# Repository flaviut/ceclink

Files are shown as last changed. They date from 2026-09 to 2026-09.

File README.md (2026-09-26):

# CECLink

The CECLink is a small device that can be used to allow a Linux computer to control a TV using the CEC protocol over HDMI. This is particularly helpful for HTPCs, which often do not have the required hardware to do so built-in.

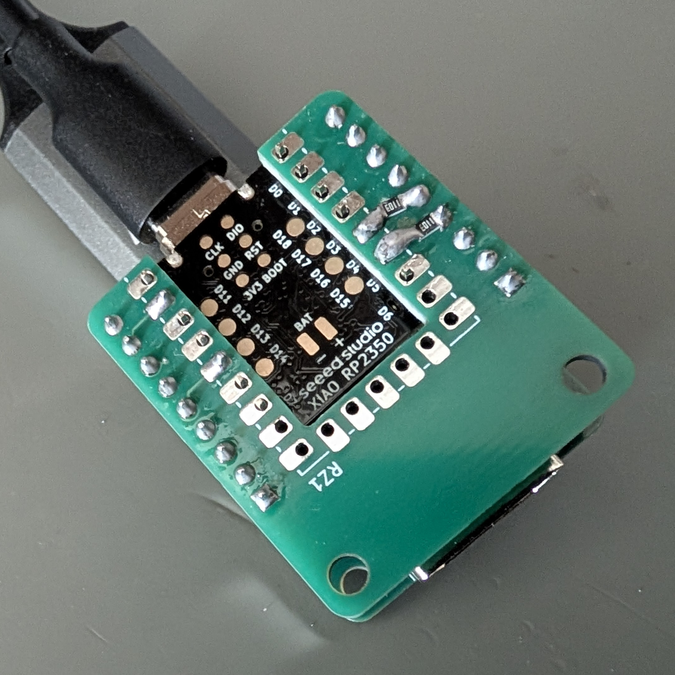
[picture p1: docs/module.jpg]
photo of the device


## Why?

What's unique about this device is that it supports higher HDMI bandwidths. It is designed to work with and tested on a 4k, 10-bit HDR, 60FPS signal. This is done through following best practices for high-speed data lines.

While others devices look like this, and are made on a standard PCB (thanks [karl for the photo](https://karlquinsland.com/pulse-eight-hdmi-cec-injector-teardown/)):

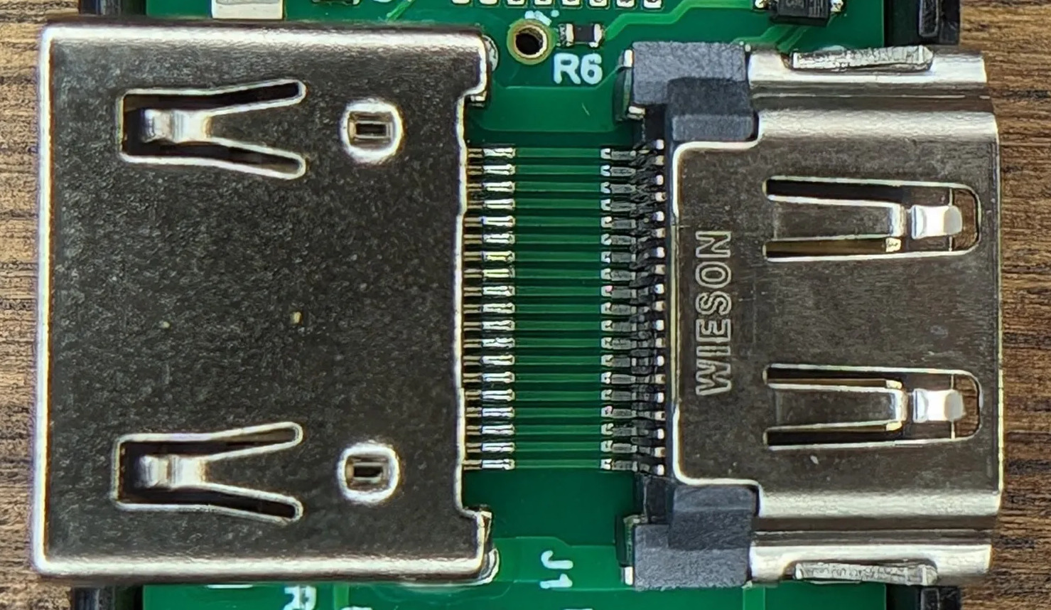
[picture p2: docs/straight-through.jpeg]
Wires passing straight through a HDMI connector


This project's design looks a little different, as it follows best practices in the dark arts of RF design:

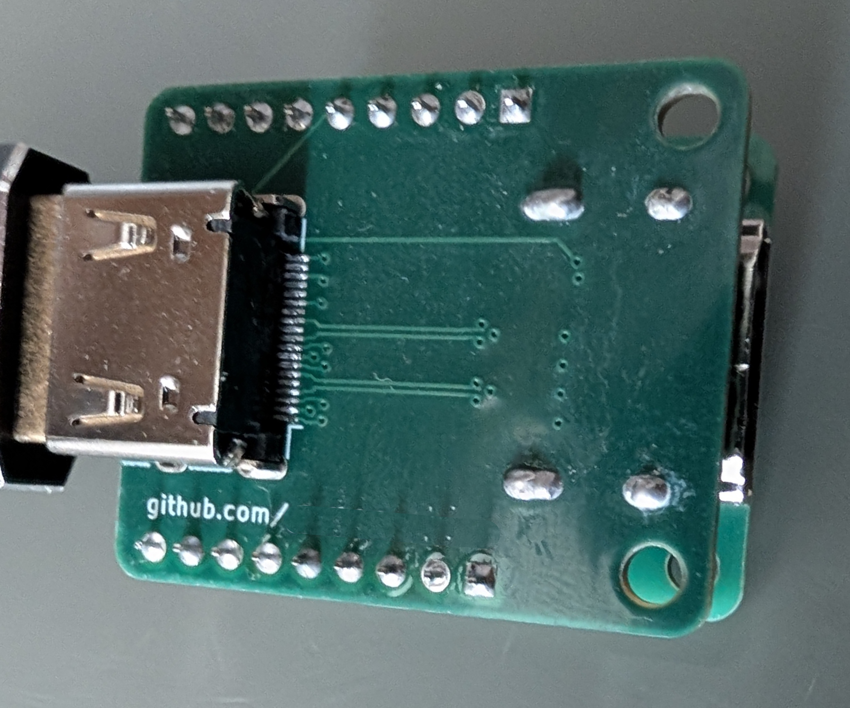
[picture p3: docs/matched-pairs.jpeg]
matched pairs for video lines


To be clear, this is not a secret technique! I would love to see others use this technique, and offer an updated commercial version of this device! All the details on how it works are in this source repo under `pcb/`, and I would be happy to talk about it.

## Making your own

### PCB

The hardware is split across two KiCad projects under [`pcb/`](pcb). You will
need to have *both* these boards produced:

* [`pcb/hdmi-breakout`](pcb/hdmi-breakout) — the HDMI passthrough that breaks
  out the CEC and DDC signals. It is a 4-layer board; order it with the
  **JLC04161H-7628 stackup**. The precise stackup is *crucial* for it to work.
* [`pcb/xiao-rp2350-adaptor`](pcb/xiao-rp2350-adaptor) — a simple breakout for the XIAO RP2350
  that connects to the HDMI breakout. This is an ordinary 2-layer board with
  no controlled-impedance requirement, so any standard stackup is fine.

The [latest release](https://github.com/flaviut/ceclink/releases/latest) has
ready-to-order Gerber and drill archives: `adapter.zip` for the XIAO RP2350 adapter
and `hdmi-breakout.zip` for the HDMI board.

Gerber and drill archives for each board can be generated with
[`jlcpcb_fab.py`](jlcpcb_fab.py).

Additional BOM (parts to source separately on top of the fabricated boards):

| Count | Part |
| ----- | ---- |
| 2 | HDMI Type-A receptacle (Molex 208658-1001, LCSC C138388) |
| 2 | 0603 100kΩ resistor |
| 1 | XIAO RP2350 |
| 2 | 1×9 2.54mm male pin header strip |
| 2 | 1×9 2.54mm female header / socket strip |
| 2 | M3 × 16mm socket head cap screw |
| 2 | M3 nut |

Remember that you can easily cut a longer 2.54mm header to size with some snips.

### Initial flash

Download `firmware.uf2` from the
[latest release](https://github.com/flaviut/ceclink/releases/latest).

Hold the BOOT button while connecting the USB cable. Once powered, you should see a new drive on your computer. Copy-paste the `.uf2` file over, and your device should be flashed.

#### CLI alternative

```sh
picotool load -v -x ceclink.uf2
```

### Operating system integration

This project tries to make use of the operating system drivers for the bulk of the integration, but this is unfortunately not fully sufficient. On Linux, `inputattach` connects the CEC serial interface to the Pulse-Eight kernel driver. A separate helper reads the HDMI physical address from the status interface and applies it to the kernel's CEC device.

#### Generic Linux installation

These instructions use systemd and udev to start the adapter automatically when it is plugged in, including after reboot.

Install the dependencies for your distribution:

| Distribution family | Install command |
| --- | --- |
| Debian / Ubuntu | `sudo apt install curl inputattach python3-serial ddcutil v4l-utils` |
| Fedora | `sudo dnf install curl linuxconsoletools python3-pyserial ddcutil v4l-utils` |
| Arch Linux | `sudo pacman -S curl linuxconsole python-pyserial ddcutil v4l-utils` |

Download the physical-address helper into `/opt/ceclink` and configure the kernel modules to load at boot:

```sh
sudo install -d -m755 /opt/ceclink
sudo curl --fail --location https://raw.githubusercontent.com/flaviut/ceclink/HEAD/nix/physical-address.py -o /opt/ceclink/physical-address.py
sudo curl --fail --location https://raw.githubusercontent.com/flaviut/ceclink/HEAD/linux/ceclink.conf -o /etc/modules-load.d/ceclink.conf
sudo modprobe pulse8-cec
sudo modprobe i2c-dev
```

If `modprobe pulse8-cec` reports that the module is missing, your kernel needs the Pulse-Eight CEC driver (`CONFIG_USB_PULSE8_CEC`). Install your distribution's additional kernel modules package or use a kernel that includes this driver before continuing.

Install the two systemd service templates. The first attaches the CEC control port to the kernel driver; the second keeps the kernel's HDMI physical address synchronized with the adapter:

```sh
sudo curl --fail --location https://raw.githubusercontent.com/flaviut/ceclink/HEAD/linux/pulse8-cec-inputattach@.service -o /etc/systemd/system/pulse8-cec-inputattach@.service

sudo curl --fail --location https://raw.githubusercontent.com/flaviut/ceclink/HEAD/linux/ceclink-physical-address@.service -o /etc/systemd/system/ceclink-physical-address@.service
```

Install the udev rules that start these services for the correct USB interfaces. Interface `00` carries CEC commands; interface `02` carries physical-address status:

```sh
sudo curl --fail --location https://raw.githubusercontent.com/flaviut/ceclink/HEAD/linux/99-ceclink.rules -o /etc/udev/rules.d/99-ceclink.rules
sudo systemctl daemon-reload
sudo udevadm control --reload-rules
```

Connect the adapter in the HDMI path, then unplug and reconnect its USB cable. udev starts both services automatically; no `systemctl enable` is needed. Check that they are running and that the CEC device has a physical address:

```sh
systemctl status 'pulse8-cec-inputattach@*' 'ceclink-physical-address@*'
sudo cec-ctl -d /dev/cec0
```

If you have multiple CEC devices, substitute the adapter's `/dev/cecN` path. To inspect service logs:

```sh
journalctl -b -u 'pulse8-cec-inputattach@*' -u 'ceclink-physical-address@*'
```

#### NixOS integration

Things are much easier on NixOS. Add this repository to your system flake's inputs:

```nix
inputs.ceclink.url = "github:flaviut/ceclink";
```

Include `ceclink` in your flake's `outputs` arguments and add its module to the host's existing `nixosSystem` module list:

```nix
outputs = { nixpkgs, ceclink, ... }: {
  nixosConfigurations.myhost = nixpkgs.lib.nixosSystem {
    modules = [
      ./configuration.nix
      ceclink.nixosModules.default
    ];
  };
};
```

## Development

### Building

```sh
nix develop
cargo build --locked --profile release-with-debug
picotool uf2 convert target/thumbv8m.main-none-eabihf/release-with-debug/ceclink -t elf ceclink.uf2
```

If direnv is enabled in your shell, run `direnv allow` once in this directory to enter the flake dev shell automatically.

For a reproducible production artifact:

```sh
nix build .#firmware
ls result/ceclink.{uf2,elf}
```

Format the Nix and Rust sources with `nix fmt`.

## Connections

| XIAO pin | RP2350 GPIO | Role |
| --- | ---: | --- |
| D9 | GPIO4 | Bidirectional CEC, open drain |
| D4 | GPIO6 | DDC SDA input only |
| D5 | GPIO7 | DDC SCL input only |

D4 and D5 are receive-only GPIO inputs, not I²C master pins. Use a 100kΩ resistor between the HDMI bus and the RP2350.

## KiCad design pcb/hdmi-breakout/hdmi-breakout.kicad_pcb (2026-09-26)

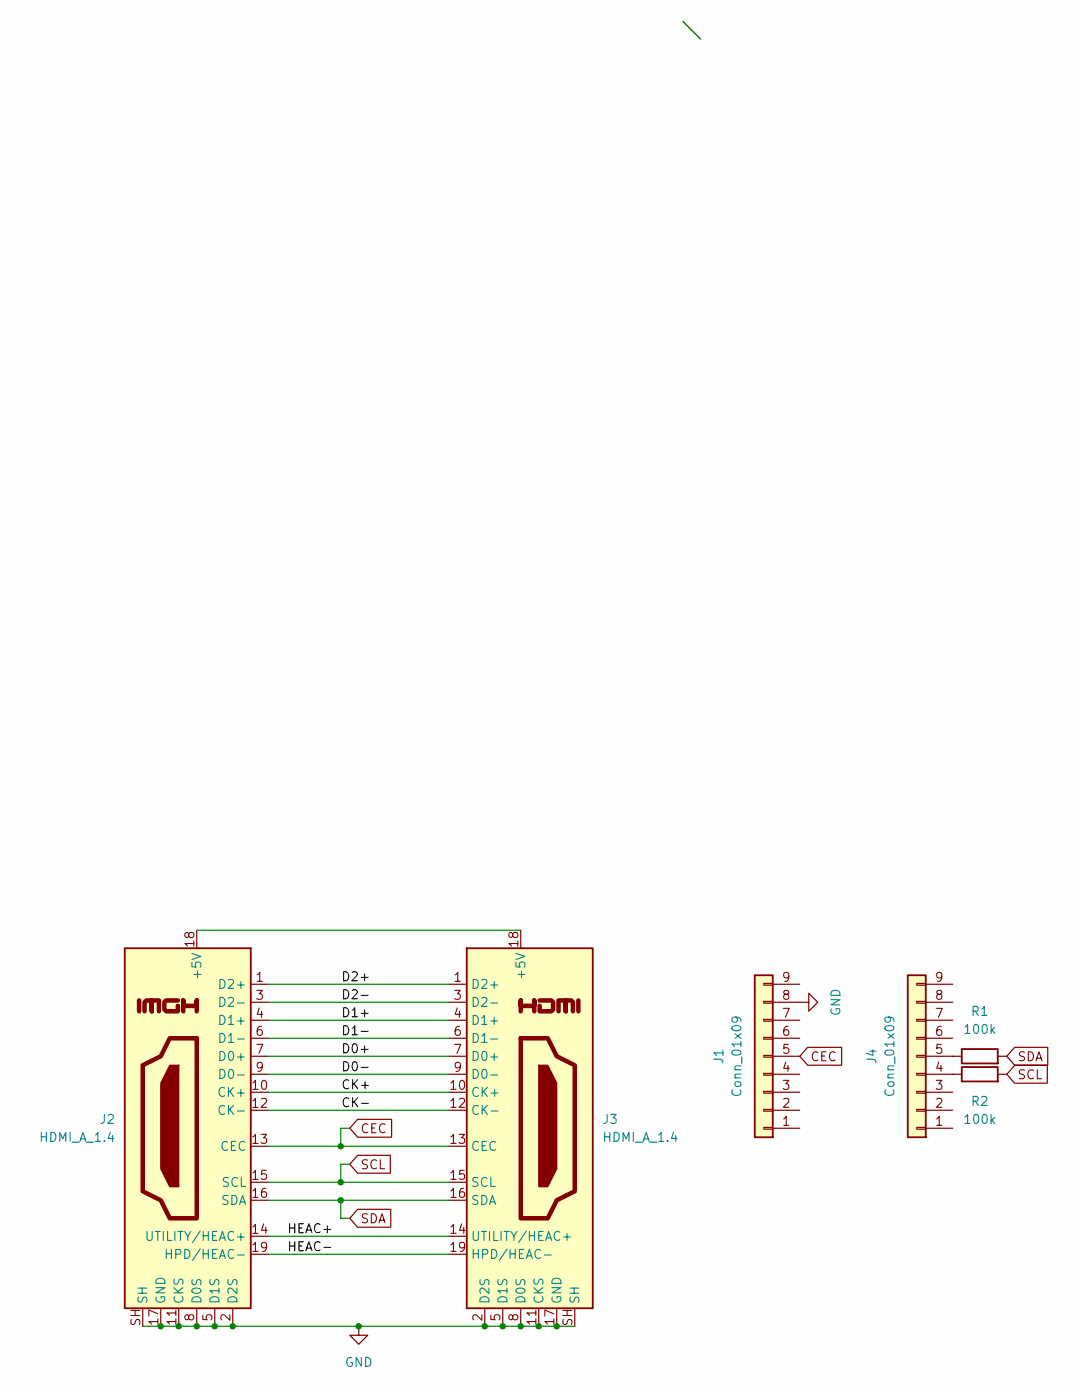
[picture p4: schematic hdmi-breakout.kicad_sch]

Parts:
J1, J4: Conn_01x09; PinHeader_1x09_P2.54mm_Vertical; LCSC C2897372
J2, J3: HDMI_A_1.4; HDMI_A_Molex_208658-1001_Horizontal; LCSC C138388
R1, R2: 100k; R_0603_1608Metric_Pad0.98x0.95mm_HandSolder; LCSC C25803

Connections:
/CK+: J2.10 (CK+), J3.10 (CK+)
/CK-: J2.12 (CK-), J3.12 (CK-)
/D0+: J2.7 (D0+), J3.7 (D0+)
/D0-: J2.9 (D0-), J3.9 (D0-)
/D1+: J2.4 (D1+), J3.4 (D1+)
/D1-: J2.6 (D1-), J3.6 (D1-)
/D2+: J2.1 (D2+), J3.1 (D2+)
/D2-: J2.3 (D2-), J3.3 (D2-)
/HEAC+: J2.14 (UTILITY/HEAC+), J3.14 (UTILITY/HEAC+)
/HEAC-: J2.19 (HPD/HEAC-), J3.19 (HPD/HEAC-)
CEC: J1.5, J2.13 (CEC), J3.13 (CEC)
GND: J1.8, J2.2 (D2S), J2.5 (D1S), J2.8 (D0S), J2.11 (CKS), J2.17 (GND), J2.SH, J3.2 (D2S), J3.5 (D1S), J3.8 (D0S), J3.11 (CKS), J3.17 (GND), J3.SH
unnamed: J2.18 (+5V), J3.18 (+5V)
unnamed: J4.4, R2.1
unnamed: J4.5, R1.1
SCL: J2.15 (SCL), J3.15 (SCL), R2.2
SDA: J2.16 (SDA), J3.16 (SDA), R1.2

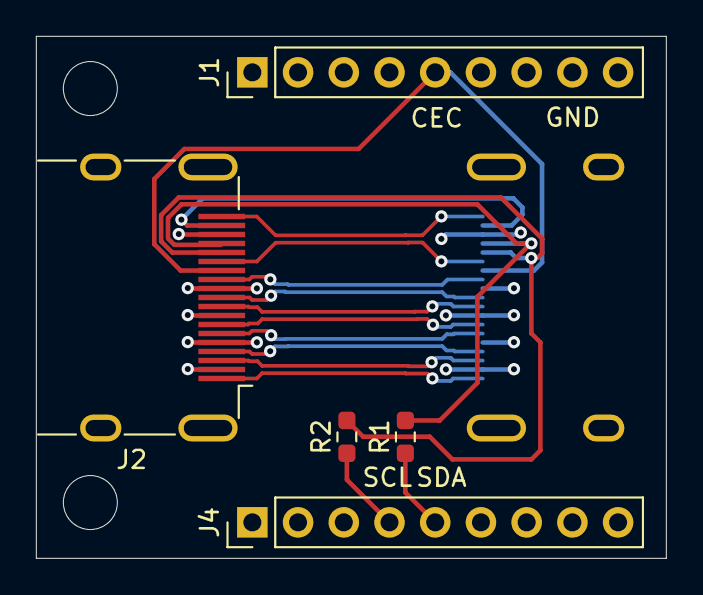
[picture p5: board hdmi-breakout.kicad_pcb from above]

Board: 4 copper layers, 35.0 x 29.0 mm, 6 parts (1 on the bottom side), 17 nets.

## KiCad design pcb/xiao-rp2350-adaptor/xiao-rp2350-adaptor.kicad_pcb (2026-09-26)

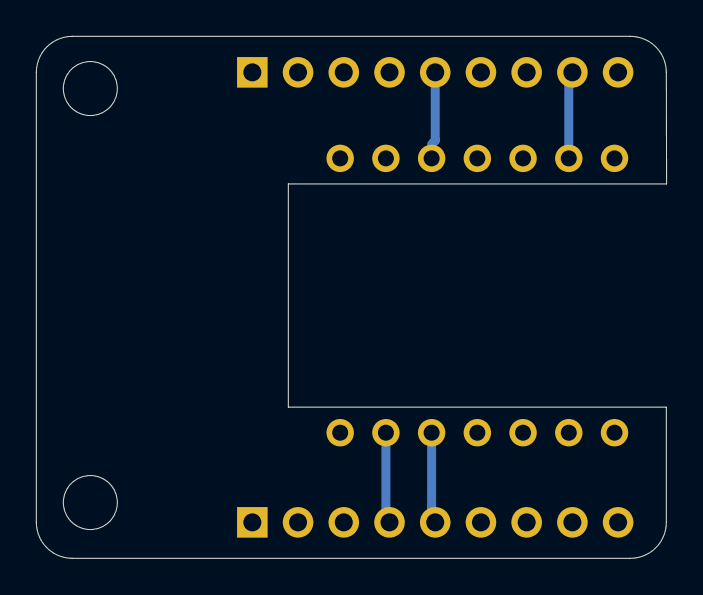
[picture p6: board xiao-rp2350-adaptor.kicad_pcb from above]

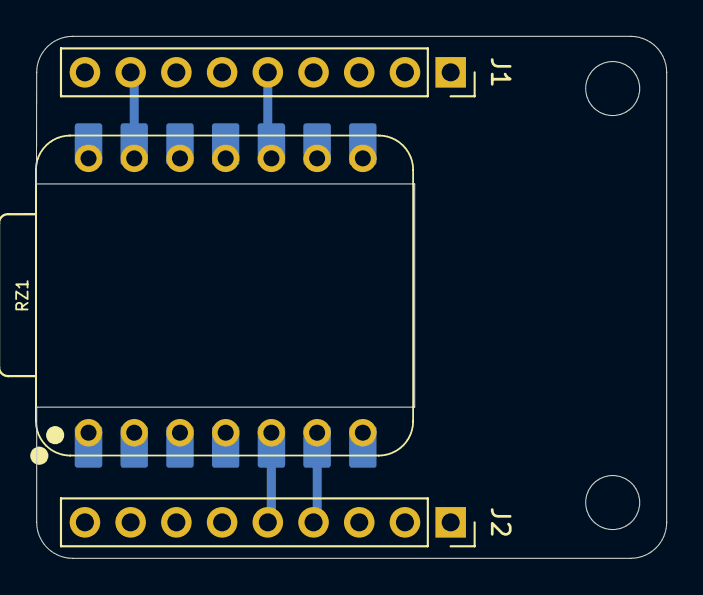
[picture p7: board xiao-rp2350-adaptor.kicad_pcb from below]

Board: 2 copper layers, 35.0 x 29.0 mm, 3 parts (3 on the bottom side), 4 nets.

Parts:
J1, J2: Conn_01x09; PinSocket_1x09_P2.54mm_Vertical
RZ1: XIAO-RP2350; XIAO-RP2350-DIP

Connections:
CEC: J1.5, RZ1.10 (GPIO4_D9_SPI0_MISO)
GND: J1.8, RZ1.13 (GND)
SCL: J2.4, RZ1.6 (GPIO7_D5_SCL1)
SDA: J2.5, RZ1.5 (GPIO6_D4_SDA1)

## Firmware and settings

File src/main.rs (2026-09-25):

#![no_std]
#![no_main]

use hal::{
    clocks::Clock,
    gpio::Pins,
    multicore::{Multicore, Stack},
    sio::Sio,
};
use panic_halt as _;
use rp235x_hal as hal;
use usb_device::{class_prelude::UsbBusAllocator, prelude::*};
use usbd_serial::SerialPort;

mod cec;
mod ddc;
mod ddc_protocol;
mod debug_port;
mod pulse8;
mod status_led;
mod transport;
mod usb_reset;

#[unsafe(link_section = ".start_block")]
#[used]
static IMAGE_DEF: hal::block::ImageDef = hal::block::ImageDef::secure_exe();
static CORE1_STACK: Stack<4096> = Stack::new();

fn usb_serial_number(buffer: &mut [u8; 16]) -> Option<&str> {
    let chip = hal::rom_data::sys_info_api::chip_info().ok().flatten()?;
    // The HAL's wafer_id field holds the high 32 bits of the RP2350 chip ID.
    for (index, word) in [chip.wafer_id, chip.device_id].into_iter().enumerate() {
        for digit in 0..8 {
            let nibble = ((word >> (28 - digit * 4)) & 0xf) as u8;
            buffer[index * 8 + digit] = if nibble < 10 {
                b'0' + nibble
            } else {
                b'A' + nibble - 10
            };
        }
    }
    core::str::from_utf8(buffer).ok()
}

#[hal::entry]
fn main() -> ! {
    let mut pac = hal::pac::Peripherals::take().unwrap();
    let mut watchdog = hal::Watchdog::new(pac.WATCHDOG);
    let clocks = hal::clocks::init_clocks_and_plls(
        12_000_000,
        pac.XOSC,
        pac.CLOCKS,
        pac.PLL_SYS,
        pac.PLL_USB,
        &mut pac.RESETS,
        &mut watchdog,
    )
    .unwrap();
    let timer = hal::Timer::new_timer0(pac.TIMER0, &mut pac.RESETS, &clocks);

    let mut sio = Sio::new(pac.SIO);
    let pins = Pins::new(
        pac.IO_BANK0,
        pac.PADS_BANK0,
        sio.gpio_bank0,
        &mut pac.RESETS,
    );
    let cec_pin = pins.gpio4.into_floating_input(); // XIAO D9
    let sda = pins.gpio6.into_floating_input(); // XIAO D4
    let scl = pins.gpio7.into_floating_input(); // XIAO D5
    let rgb_data = pins.gpio22.into_floating_input();
    let rgb_power = pins.gpio23.into_floating_input();
    let mut led = status_led::StatusLed::new(
        rgb_data,
        rgb_power,
        pac.PIO1,
        &mut pac.RESETS,
        clocks.system_clock.freq().to_Hz(),
    );
    let mut ddc = ddc::init(sda, scl, pac.PIO0, &mut pac.RESETS);
    unsafe {
        hal::arch::interrupt_enable();
    }

    let mut multicore = Multicore::new(&mut pac.PSM, &mut pac.PPB, &mut sio.fifo);
    let usb_timer = timer;
    multicore.cores()[1]
        .spawn(CORE1_STACK.take().unwrap(), move || {
            cec::run(cec_pin, timer)
        })
        .unwrap();

    let usb_bus = UsbBusAllocator::new(hal::usb::UsbBus::new(
        pac.USB,
        pac.USB_DPRAM,
        clocks.usb_clock,
        true,
        &mut pac.RESETS,
    ));
    let mut serial =
        SerialPort::new_with_interface_names(&usb_bus, Some("Pulse-Eight CEC control"), None);
    let mut debug_serial =
        SerialPort::new_with_interface_names(&usb_bus, Some("CECLink status"), None);
    let mut usb_reset = usb_reset::UsbReset::new(&usb_bus);
    let mut serial_number_buffer = [0u8; 16];
    let mut strings = StringDescriptors::default()
        .manufacturer("CECLink")
        .product("RP2350 HDMI CEC Adapter");
    if let Some(serial_number) = usb_serial_number(&mut serial_number_buffer) {
        strings = strings.serial_number(serial_number);
    }
    let mut device = UsbDeviceBuilder::new(&usb_bus, UsbVidPid(0x2548, 0x1002))
        .strings(&[strings])
        .unwrap()
        .composite_with_iads()
        .device_release(0x0010) // USB BCD version shown by fwupd.
        .build();

    let mut protocol = pulse8::Protocol::new();
    let mut pending_output = None;
    let mut debug_output = debug_port::DebugOutput::new();
    let mut usb_bootsel_requested_at = None;
    loop {
        ddc.poll();
        led.update(ddc.led_state());
        let _ = device.poll(&mut [&mut serial, &mut debug_serial, &mut usb_reset]);
        let mut bytes = [0u8; 64];
        if let Ok(count) = serial.read(&mut bytes) {
            for &byte in &bytes[..count] {
                protocol.input_byte(byte);
            }
        }
        while let Some(event) = transport::pop_event() {
            protocol.event(event);
        }
        protocol.set_physical_address(ddc.physical_address());
        let mut debug_bytes = [0u8; 32];
        if let Ok(count) = debug_serial.read(&mut debug_bytes) {
            for &byte in &debug_bytes[..count] {
                debug_output.input_byte(byte);
            }
        }
        debug_output.poll(&mut debug_serial, usb_timer.get_counter().ticks(), &ddc);
        if usb_reset.take_bootsel_request() {
            usb_bootsel_requested_at = Some(usb_timer.get_counter_low());
        }
        let usb_bootsel_ready = usb_bootsel_requested_at
            .is_some_and(|at| usb_timer.get_counter_low().wrapping_sub(at) >= 50_000);
        if usb_bootsel_ready {
            hal::reboot::reboot(
                hal::reboot::RebootKind::BootSel {
                    picoboot_disabled: false,
                    msd_disabled: false,
                },
                hal::reboot::RebootArch::Arm,
            );
        }
        if pending_output.is_none() {
            pending_output = protocol.next_output();
        }
        if let Some(byte) = pending_output {
            if serial.write(&[byte]).is_ok() {
                pending_output = None;
            }
        }
    }
}

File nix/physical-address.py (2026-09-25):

"""Apply CECLink status records to the Linux CEC adapter on the same USB device."""

import argparse
import array
import fcntl
import logging
import os
import subprocess
import time
from pathlib import Path


# Linux CEC UAPI ioctl numbers on the supported x86_64 and aarch64 systems.
CEC_ADAP_G_PHYS_ADDR = 0x80026101
CEC_ADAP_S_PHYS_ADDR = 0x40026102
UNKNOWN_ADDRESS = 0xFFFF
MAX_EDID_READS = 3
EDID_RETRY_DELAY = 5.0


def parse_status(line):
    try:
        fields = dict(field.split("=", 1) for field in line.decode("ascii").strip().split("\t"))
        if set(fields) != {"status_version", "physical_address"}:
            return None
        if fields["status_version"] != "1":
            return None
        address = int(fields["physical_address"])
    except (UnicodeError, ValueError):
        return None
    if not 0 <= address <= 0xFFFF:
        return None
    if address != 0xFFFF:
        zero = False
        for shift in (12, 8, 4, 0):
            nibble = (address >> shift) & 15
            if zero and nibble:
                return None
            zero |= nibble == 0
    return address


def usb_parent(path):
    path = path.resolve(strict=True)
    for parent in (path, *path.parents):
        if (parent / "idVendor").exists() and (parent / "idProduct").exists():
            return parent
    raise OSError(f"No USB parent for {path}")


def cec_sysfs_path(device, sysfs):
    number = device.stat().st_rdev
    return sysfs / "dev/char" / f"{os.major(number)}:{os.minor(number)}"


def matching_cec(tty, sysfs=Path("/sys"), devices=Path("/dev")):
    usb = usb_parent(sysfs / "class/tty" / tty)
    matches = []
    for device in devices.glob("cec*"):
        if not device.name[3:].isdigit():
            continue
        try:
            if usb_parent(cec_sysfs_path(device, sysfs)) == usb:
                matches.append(device)
        except OSError:
            continue
    # Never guess if a driver has not attached or multiple adapters match.
    return matches[0] if len(matches) == 1 else None


def apply_address(device, address):
    with device.open("rb+", buffering=0) as port:
        current = array.array("H", [0])
        fcntl.ioctl(port, CEC_ADAP_G_PHYS_ADDR, current, True)
        if current[0] == address:
            return False
        fcntl.ioctl(port, CEC_ADAP_S_PHYS_ADDR, array.array("H", [address]))
    return True


def synchronize(tty, address):
    device = matching_cec(tty)
    if device is not None and apply_address(device, address):
        logging.info("%s physical address: %04x", device, address)


class AddressFilter:
    """Let EDID rereads finish before publishing a topology change."""

    def __init__(self):
        self.candidate = None
        self.since = 0.0

    def settled(self, address, now):
        if address != self.candidate:
            self.candidate = address
            self.since = now
        delay = 2.0 if address == 0xFFFF else 0.5
        return now - self.since >= delay


class EdidRecovery:
    """Bound active reads while firmware has not captured an address."""

    def __init__(self):
        self.attempts = 0
        self.next_attempt = 0.0

    def observe(self, address, now):
        if address != UNKNOWN_ADDRESS:
            self.attempts = 0
            self.next_attempt = 0.0
            return False
        if self.attempts >= MAX_EDID_READS or now < self.next_attempt:
            return self.attempts < MAX_EDID_READS or now < self.next_attempt
        self.attempts += 1
        try:
            result = subprocess.run(
                [
                    "ddcutil",
                    "--edid-read-size=256",
                    "--disable-try-get-edid-from-sysfs",
                    "detect",
                ],
                capture_output=True,
                timeout=20,
                check=False,
            )
            # detect scans every display bus. Some displays lack DDC/CI;
            # firmware status confirms whether EDID contained an address.
            logging.info("DDC EDID scan exited %d", result.returncode)
        except (OSError, subprocess.TimeoutExpired) as error:
            logging.warning("DDC EDID read deferred: %s", error)
        self.next_attempt = time.monotonic() + EDID_RETRY_DELAY
        return True


def ready_address(address_filter, recovery, address, now):
    # A DDC read briefly clears the firmware address. Wait for the status to
    # settle before starting another read or resetting the retry budget.
    if not address_filter.settled(address, now):
        return None
    if recovery.observe(address, now):
        return None
    return address


def main():
    import serial

    parser = argparse.ArgumentParser(description=__doc__)
    parser.add_argument("tty", help="CECLink status TTY name, e.g. ttyACM1")
    args = parser.parse_args()
    logging.basicConfig(level=logging.INFO, format="%(message)s")
    address_filter = AddressFilter()
    recovery = EdidRecovery()
    # pyserial asserts DTR so the device emits status records.
    with serial.Serial(f"/dev/{args.tty}", timeout=2, exclusive=True) as port:
        while True:
            line = port.read_until(b"\n", size=1024)
            if not line.endswith(b"\n"):
                continue
            address = parse_status(line)
            if address is None:
                continue
            now = time.monotonic()
            address = ready_address(address_filter, recovery, address, now)
            if address is None:
                continue
            try:
                synchronize(args.tty, address)
            except OSError as error:
                # The next periodic record retries device enumeration and
                # address writes, even if the physical address is unchanged.
                logging.warning("Physical address update deferred: %s", error)


if __name__ == "__main__":
    main()

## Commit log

2026-09-25 Use binary serde for Pulse-Eight wire payloads
2026-09-25 Simplify Pulse-Eight wire encoding
2026-09-25 Package Pulse-Eight CEC driver as kernel module overlay
2026-09-25 Fix automatic EDID recovery after firmware restart
    [physical-address.py]
2026-09-25 update docs
    [hdmi-breakout.kicad_pcb, hdmi-breakout.kicad_sch, hdmi-breakout.sch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]
2026-09-25 correct hardware bugs
    [hdmi-breakout.kicad_pcb, hdmi-breakout.kicad_sch, rp2040-adaptor.kicad_pcb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]
2026-09-25 update name
    [hdmi-breakout.kicad_pcb]
2026-09-26 clarify docs
    [xiao-rp2350-adaptor.kicad_pcb, xiao-rp2350-adaptor.kicad_sch]
2026-09-26 update BOM
    [hdmi-breakout.kicad_pcb, hdmi-breakout.kicad_sch]
2026-09-26 Include HDMI SMT BOM and CPL in release archive
